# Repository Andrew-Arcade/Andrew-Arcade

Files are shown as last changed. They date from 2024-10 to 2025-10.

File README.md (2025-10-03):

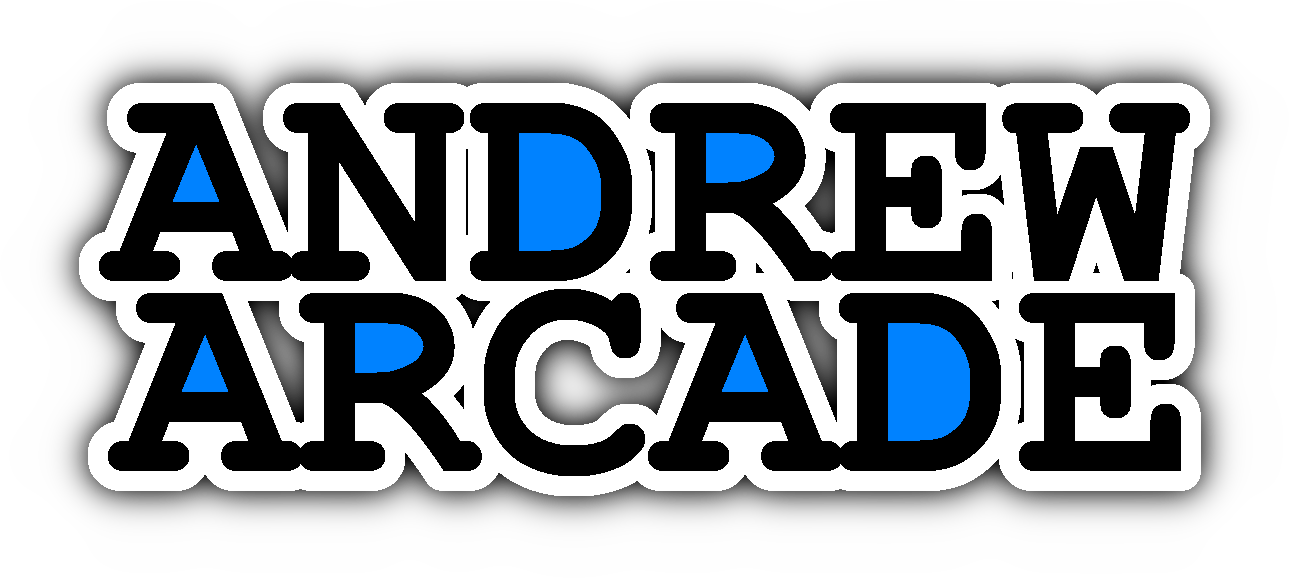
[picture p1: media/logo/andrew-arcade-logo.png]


Check out my progress in the [journal](JOURNAL.md)!

<!-- ### About Andrew Arcade

Andrew Arcade is a custom game console built with a Raspberry Pi 5 running Linux. Its main purpose is to play Unity games that I have created.

Since the Raspberry Pi 5 uses an ARM processor, Unity games can't be compiled to run on it directly. To solve this, we use a tool called Box64, which lets us run Unity games and apps on the Raspberry Pi by emulating the required architecture.

### Version 2

Version 2 of Andrew Arcade will feature a redesigned case. My goal is to make it more comfortable to use and to improve some of the mounting parts that didn’t work well in the first version. -->

## About the Project

Custom game console designed to run my Unity games.

Designed on top of the Raspberry Pi 5 running pios.

We use [box64](https://github.com/ptitSeb/box64) to run Unity games on the ARM architecture. 

## Apps
[Andrew-Arcade-Apps](https://github.com/AndrewCromar/Andrew-Arcade-Apps) (referred to as "apps repository")
> Most up to date information will be in the apps repository eventually.

### How to contribute your app

To create your own app, you'll need to submit all the source code (the full Unity project) to the apps repository. You will also need to modify the driver app to include your app (details will be provided later). Once your app is ready for release, submit a pull request (PR) to the apps repository. After your PR is approved, you can build the app and submit a second PR to this main Andrew Arcade repository.

### App file structure

Go to the [software/apps](software/apps) directory and create a new folder. Name the folder after your app using camelCase (no spaces, capitalize the first letter of each new word except for the first one). Then, place your app's build files inside the folder you just created.

### Why maintain a second repository?

Unity projects typically require a large amount of storage, while Raspberry Pi 5 devices often have limited space. As a result, the source code for the apps doesn't need to be stored directly on the device.

### More app information

For additional details about the apps or games, check out the [Andrew Arcade Apps](https://github.com/AndrewCromar/Andrew-Arcade-Apps) repository.

## BOM
> [!WARNING]
> I need to update this it is not correct atm.

- You will want an assortment of M3 screws.
- You will need to order your own pcbs (manufacturing files/instructions will come later).

| Name | URL | Notes |
|---|---|---|
| Raspberry Pi 5 | [link](https://www.raspberrypi.com/products/raspberry-pi-5/) | |
| Waveshare RP2040-Zero | [link](https://www.amazon.com/dp/B09L4YNNQH?ref_=cm_sw_r_cp_ud_ct_66QWR2T5E030FK6R5A1J_3&th=1) | Purchase with headers pre-soldered for easier assembly. |
| Adafruit HDMI Display | [link](https://www.adafruit.com/product/2232) | - Resolution: 800x480.<br> - Size: 5 inches. |
| Buttons | [link](https://www.amazon.com/dp/B08R9P3RKM?ref_=cm_sw_r_cp_ud_ct_66QWR2T5E030FK6R5A1J_6&th=1) | You need at least 11 buttons. You do not want them to be pre-wired. |
| Joysticks | [link](https://www.adafruit.com/product/512) | Soldering is required for assembly. |
| 90 Degree Headers | [link](https://www.amazon.com/PATIKIL-Header-Single-2-54mm-Plated/dp/B0C81QTKC5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) | Used to connect the joysticks to the board. |
| Button Wires | [link](https://www.amazon.com/dp/B092CW94LK?ref_=cm_sw_r_cp_ud_ct_66QWR2T5E030FK6R5A1J_5&th=1) | You need at least 11. |
| JST Connectors | [link](https://www.amazon.com/dp/B0B2R966ZY?ref_=cm_sw_r_cp_ud_ct_66QWR2T5E030FK6R5A1J_4&th=1) | - Size: 2P.<br> - Style: XH.

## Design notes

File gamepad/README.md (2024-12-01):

# How to build your gamepad.

> I may make a better version of these instructions later.

1. Gather parts.
    - Get a Raspberry Pi Pico.
    - Get six buttons.
    - Get a joystick module.
2. Wire it according to the schematic.
    - pcb/schematic.pdf
3. Install the firmware.
    - _firmware/GP2040-CE_0.7.10_Pico.uf2
4. Set the pin mappings for the controller according to my image.
    - pin-mappings.png
5. Done! You should have six buttons and the joystick.

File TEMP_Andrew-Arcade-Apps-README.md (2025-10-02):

# Andrew Arcade Apps
A collection of apps for Andrew Arcade.

> More instructions and information will be provided when the project is ready for public contributions.

---

## How to Contribute Your App
To add your app to Andrew Arcade:

1. **Upload Your App Source Code**  
   - Submit the complete source code for your app (your full Unity project) to the apps repository.

2. **Modify the Driver App**  
   - Follow the steps below to add your app to the driver app.

3. **Submit Pull Requests (PRs)**  
   - Once your app is integrated into the driver app, submit a pull request to the apps repository for review.  
   - After approval, build your app and submit a second PR to the main Andrew Arcade repository.

---

## Adding Your App to the Driver App

### 1. Upload Your App Icon
- Navigate to the [Icons folder](https://github.com/AndrewCromar/Andrew-Arcade-Apps/tree/main/Driver/Assets/Resources/Apps/Icons).
- Add your app's icon (image file) to this folder.

### 2. Fix the Icon Resolution
- Ensure your icon is a square image (width and height must be equal).  
- Note your icon's dimensions (e.g., 128x128 pixels).  
- Open the Unity project for the driver app.  
- In Unity, go to **Resources/Apps/Icons** and locate your icon.  
- Select your icon and update the **Pixels Per Unit** setting to match your icon's dimensions (e.g., set **Pixels Per Unit** to `128` if your icon is 128x128).

### 3. Create a JSON File for Your App
- Navigate to the [Apps folder](https://github.com/AndrewCromar/Andrew-Arcade-Apps/tree/main/Driver/Assets/Resources/Apps).
- Create a new JSON file named after your app, using camelCase (e.g., `myApp.json`).

### 4. Edit the JSON File
- Open the JSON file you just created.
- Use the following template and replace the placeholders with your app's details:
  ```json
  {
      "title": "Your App Name",
      "developer": "Your Developer Name",
      "icon": "icons/[your-icon-name]"
  }

- Replace [your-icon-name] with your icon's filename, including its extension.

### 5. Submit a Pull Request for the Driver App
- After completing the above steps, submit a pull request to the apps repository.
- Once approved, your app will be included in the driver app.

---

# What is camelCase?
**camelCase** is a way of naming files, variables, or other elements where:

- The first word is written in lowercase.
- Each subsequent word starts with an uppercase letter, with no spaces or underscores between words.

### Examples:
- myApp
- weatherForecast
- gameSettings

Using camelCase ensures names are readable, concise, and consistent.

---

Follow these steps carefully to contribute your app successfully. Let me know if further clarification is needed!

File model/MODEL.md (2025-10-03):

# Models

[Onshape CAD](https://cad.onshape.com/documents/3db21cff3a2dcf8b652a7395/w/82a6a37a568c22dcd730e9cf/e/2649efe94d90b2f031aeb237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)

The only tool you will need is a 3d printer as everything is 3d printable for the assemble of Andrew Arcade, the only thing not 3d printable is the pcb. 

In the future I will make instructions with images but for now just use the master assembly in the onshape design as reference.

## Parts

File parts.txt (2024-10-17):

Raspberry Pi 5 - https://www.raspberrypi.com/products/raspberry-pi-5/
	- Price: $80.

Adafruit HDMI Display - https://www.adafruit.com/product/2232
	- Price: $60.
	- Dimensions: 800x480
	- Size: 5".

Power Button:
	- 17.3 mm max diameter
	- 13.0 mm fit diameter
	- 21.4 mm height
	- 8.3 mm height (top of button to skinny part)

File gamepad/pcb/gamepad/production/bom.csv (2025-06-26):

Designator | Footprint | Quantity | Value | LCSC Part #
CARDINAL_DOWN1, CARDINAL_LEFT1, CARDINAL_RIGHT1, CARDINAL_UP1, DPAD_EAST1, DPAD_NORTH1, DPAD_SOUTH1, DPAD_WEST1, OPERATORS_MINUS1, OPERATORS_PLUS1 | JST_XH_B2B-XH-A_1x02_P2.50mm_Vertical | 10 | Conn_01x02
JOYSTICK_LEFT1, JOYSTICK_RIGHT1 | JST_PH_B5B-PH-K_1x05_P2.00mm_Vertical | 2 | Conn_01x05
U3 | MODULE_RP2040-ZERO | 1 | RP2040-ZERO

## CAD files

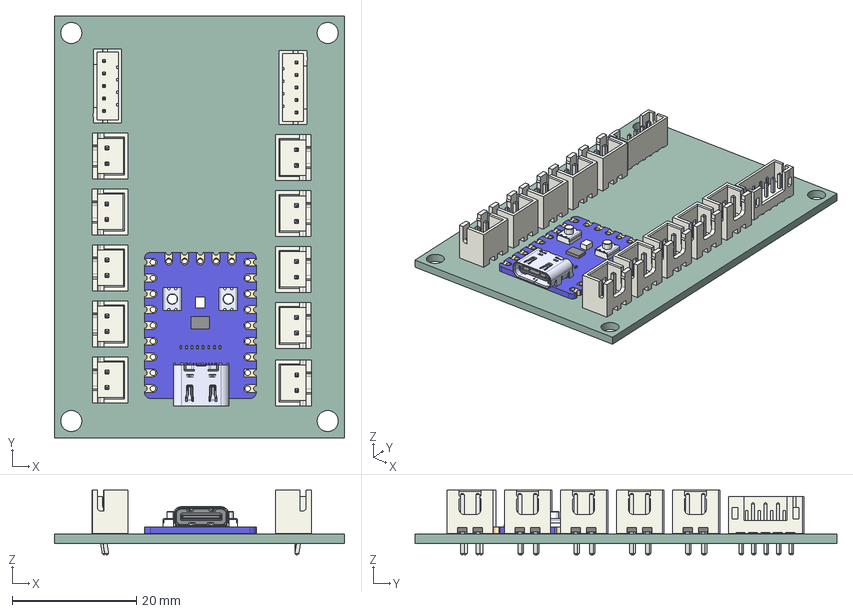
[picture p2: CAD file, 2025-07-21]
gamepad/pcb/gamepad.step
46.6 x 67.8 x 10.4 mm
JST_XH_B2B-XH-A_1x02_P2.50mm_Vertical x 10
JST_PH_B5B-PH-K_1x05_P2.00mm_Vertical x 2
RP2040-ZERO
gamepad_PCB

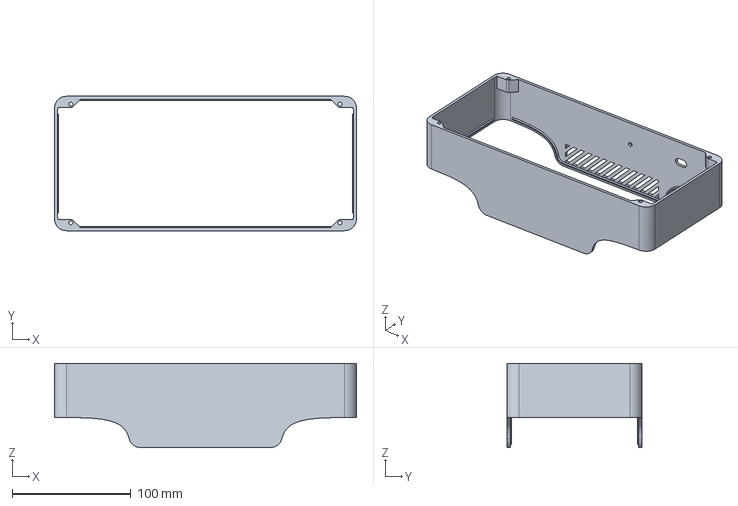
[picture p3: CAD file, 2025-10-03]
model/Wall.step
254.0 x 113.1 x 70.8 mm

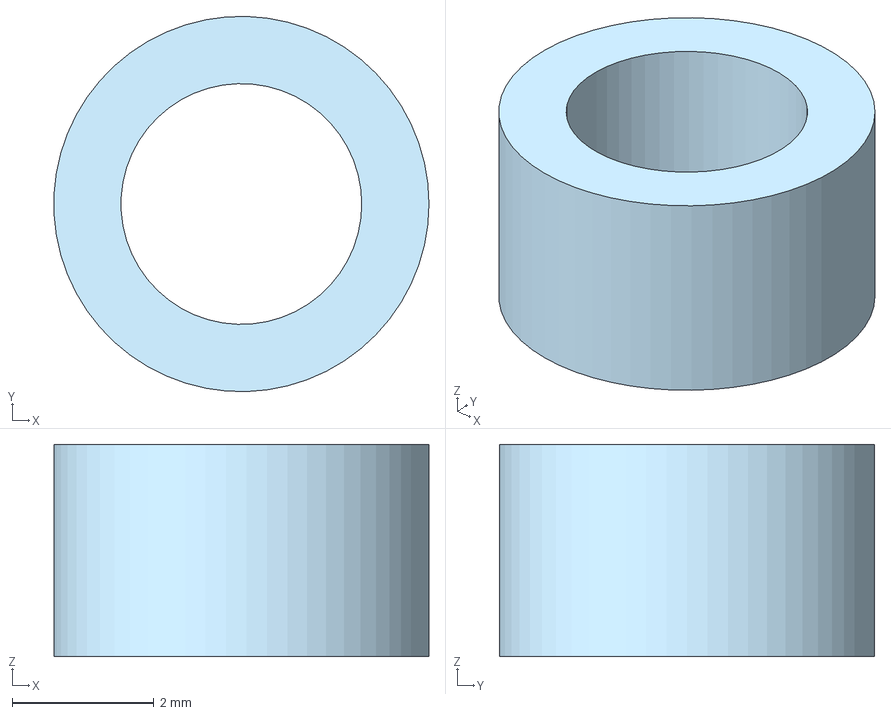
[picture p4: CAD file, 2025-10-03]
model/Spacers - Pi5 Spacer Top.step
5.30 x 5.30 x 3.00 mm

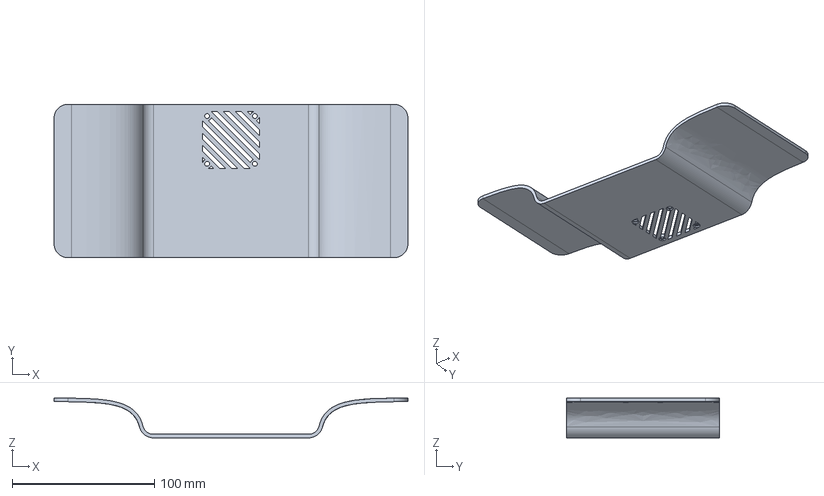
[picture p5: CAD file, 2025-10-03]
model/Back Plate.step
248.7 x 107.8 x 27.9 mm

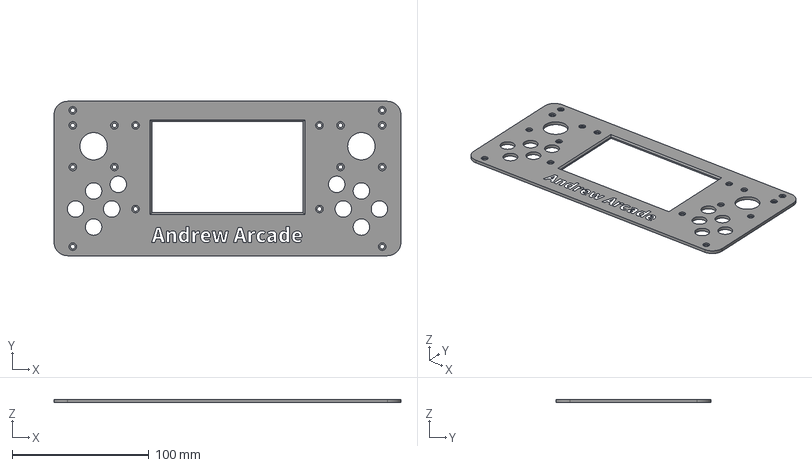
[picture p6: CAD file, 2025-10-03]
model/Front Panel.step
254.0 x 113.1 x 2.54 mm

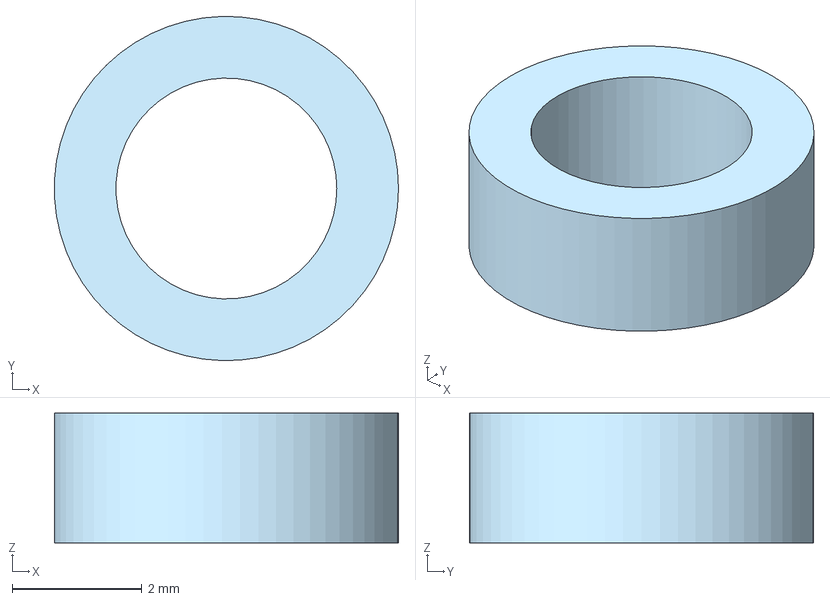
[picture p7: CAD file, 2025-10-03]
model/Spacers - Pi5 Spacer Bottom.step
5.30 x 5.30 x 2.00 mm

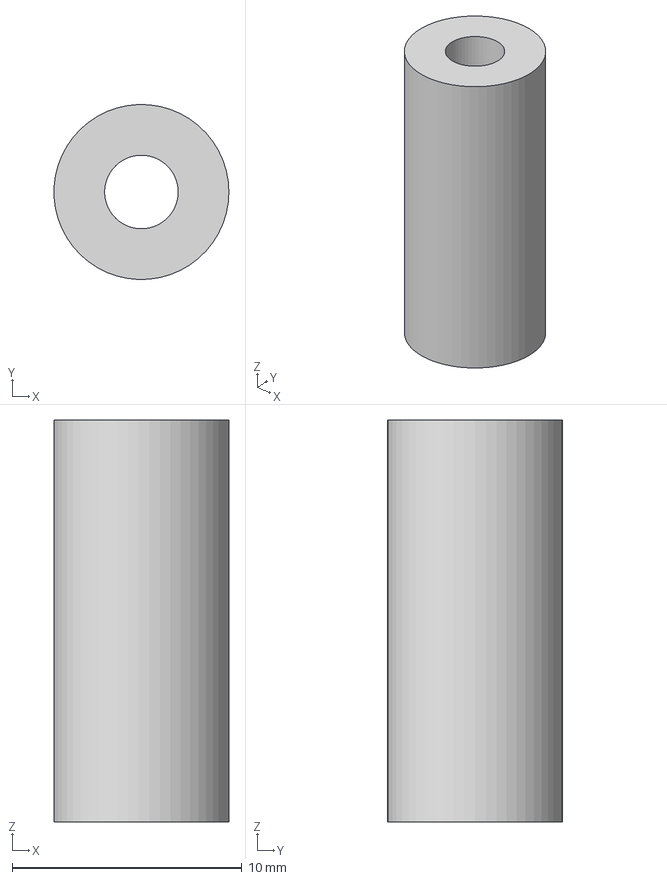
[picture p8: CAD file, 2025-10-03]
model/Joystick Mount.step
7.61 x 7.62 x 17.5 mm

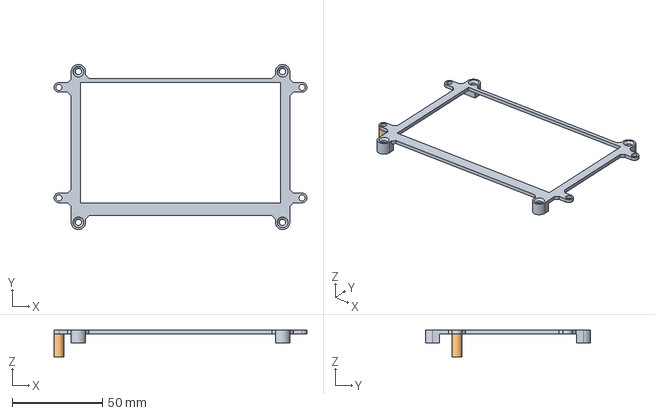
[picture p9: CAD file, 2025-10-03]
model/Display Mount.step
140.0 x 91.4 x 14.8 mm

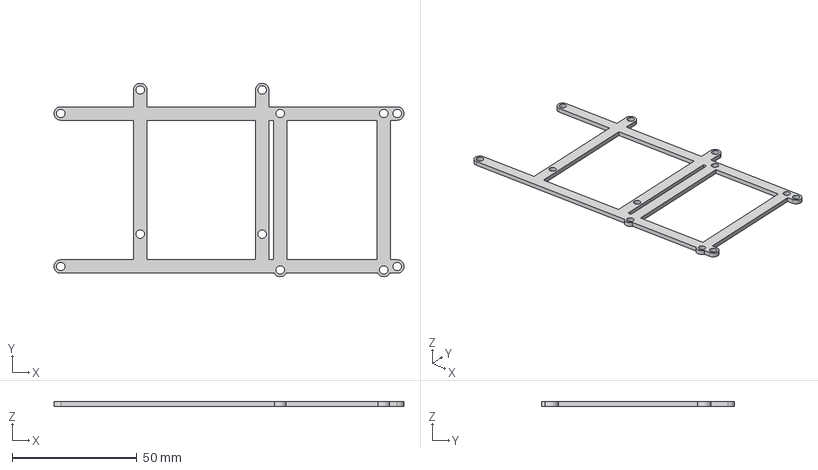
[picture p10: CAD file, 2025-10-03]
model/Pis Mount.step
140.0 x 77.4 x 2.00 mm

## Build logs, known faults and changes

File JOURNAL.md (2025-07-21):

---
title: "Andrew Arcade"
author: "Andrew Cromar"
description: "A custom game console designed to run Unity Games."
created_at: "2025-05-22"
---

# July 21th: Redesigned the PCB to be smaller.

- I had to move the rp5 over a bit so I needed to make the pcb smaller.

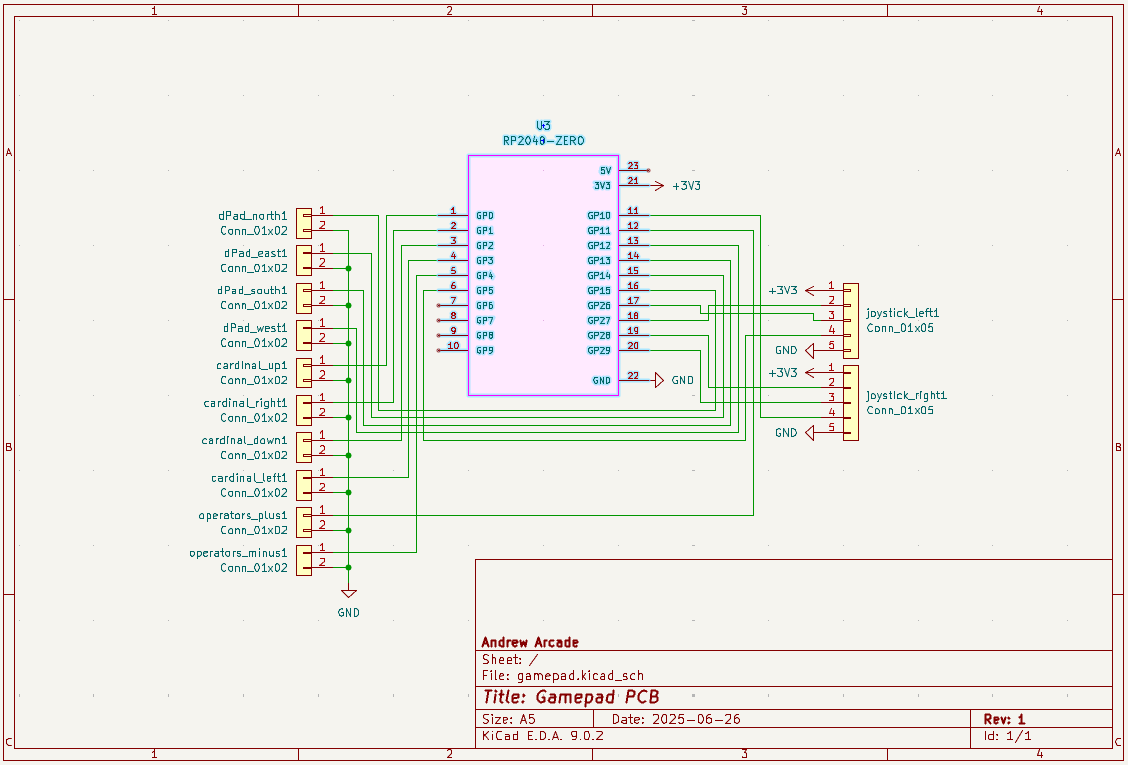
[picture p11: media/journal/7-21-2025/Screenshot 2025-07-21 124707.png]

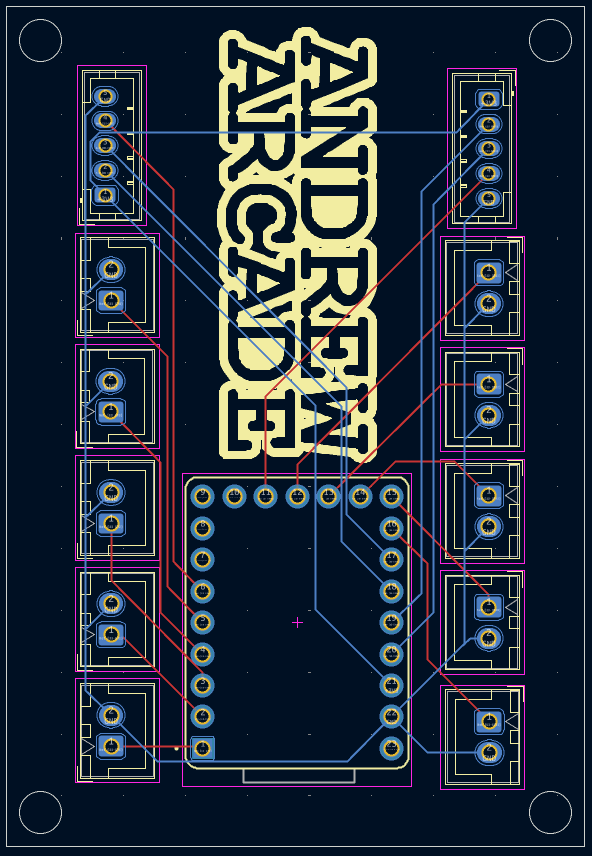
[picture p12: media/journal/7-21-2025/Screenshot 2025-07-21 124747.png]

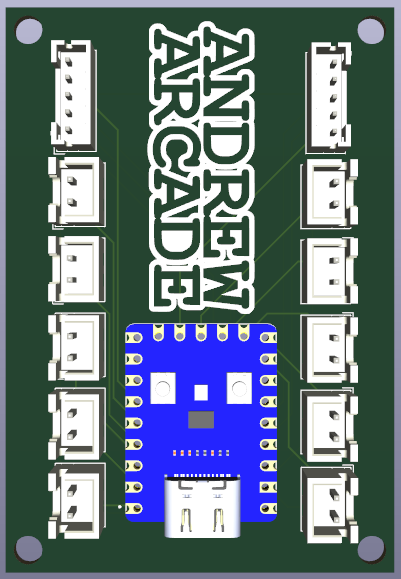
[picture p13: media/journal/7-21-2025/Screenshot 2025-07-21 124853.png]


**Total time spent: 2 hours**

# June 25th: Made a few updates to different parts.

- I updated the layout of the front panel.
    - I still am not 100% happy with where the +/- buttons are but It's good enough for now.
- I updated the pcb to work with all the buttons and to have more ideally placed connectors.

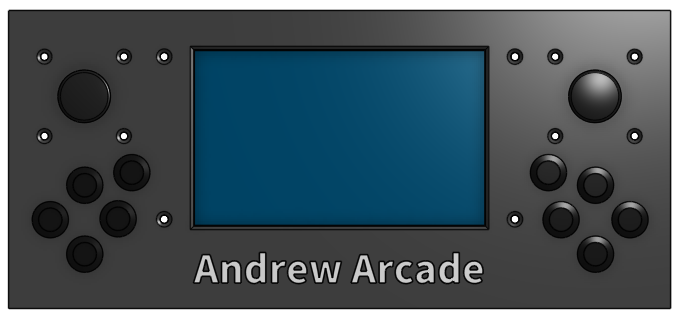
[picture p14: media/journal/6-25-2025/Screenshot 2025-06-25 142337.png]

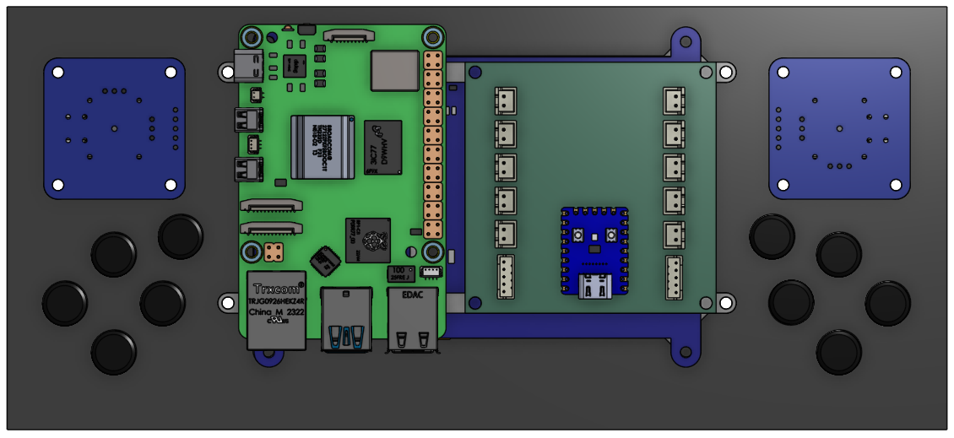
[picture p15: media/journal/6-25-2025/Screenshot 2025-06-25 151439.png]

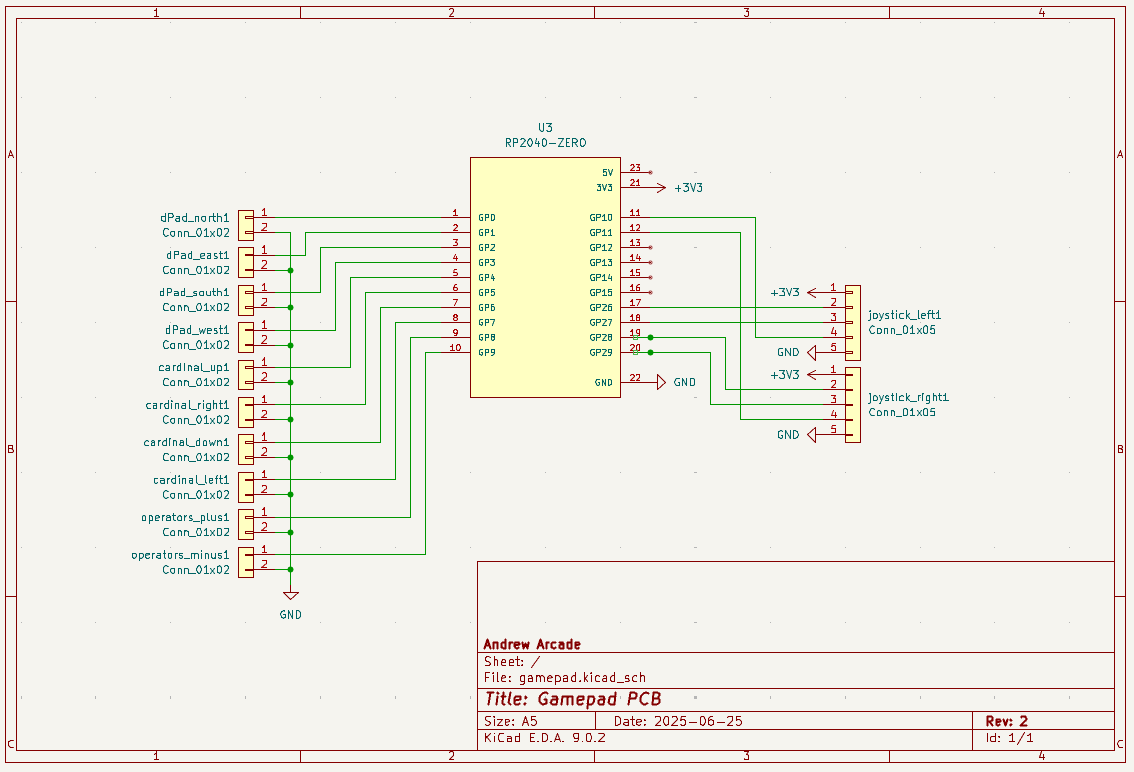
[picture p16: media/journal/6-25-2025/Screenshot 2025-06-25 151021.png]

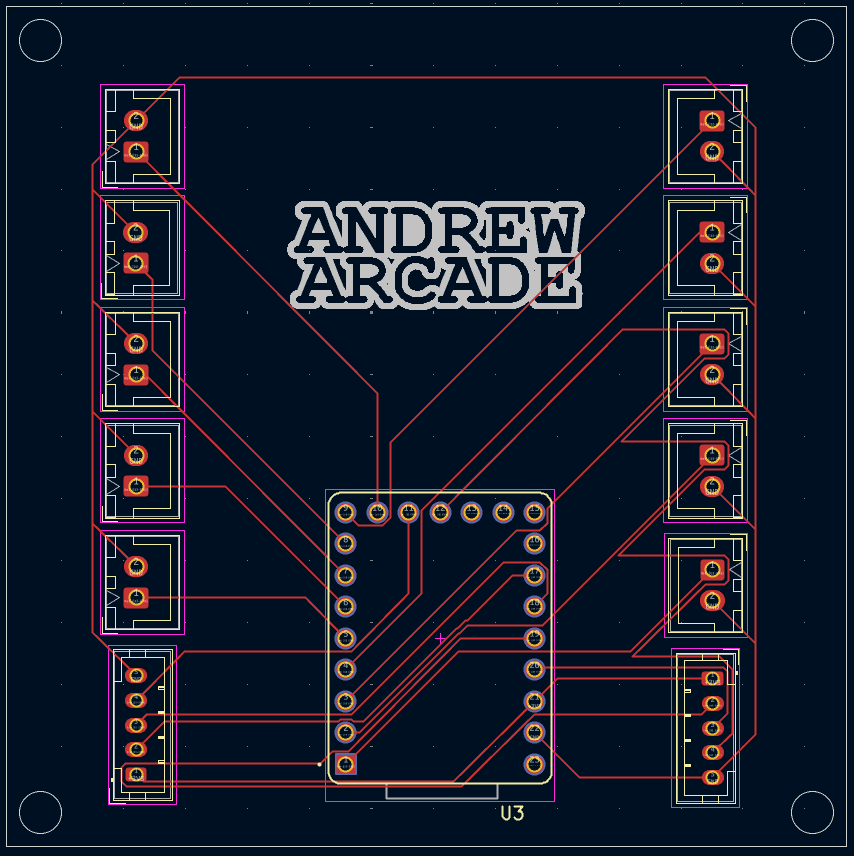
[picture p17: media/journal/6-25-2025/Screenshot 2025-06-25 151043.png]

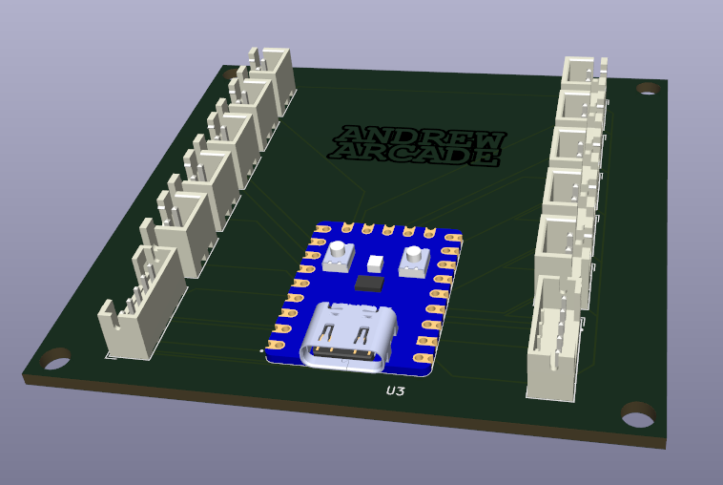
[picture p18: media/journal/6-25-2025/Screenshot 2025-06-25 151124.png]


**Total time spent: 2 hours**

# June 4th: Decided to switch to a Waveshare Zero.

- I wanted to use two joysticks for my project, but the Raspberry Pi Pico didn’t have enough analog pins. So, I switched to the Waveshare 2040 Zero, which uses the same RP2040 chip as the Pico but provides 4 analog pins, enough for both joysticks (2 pins each for X and Y on both the left and right joysticks).
- I updated the PCB design to use the new board. This involved finding the correct footprints, symbols, and a CAD model for the Waveshare 2040 Zero.
- I’ve updated the schematic, but I haven’t finished routing the PCB traces yet.

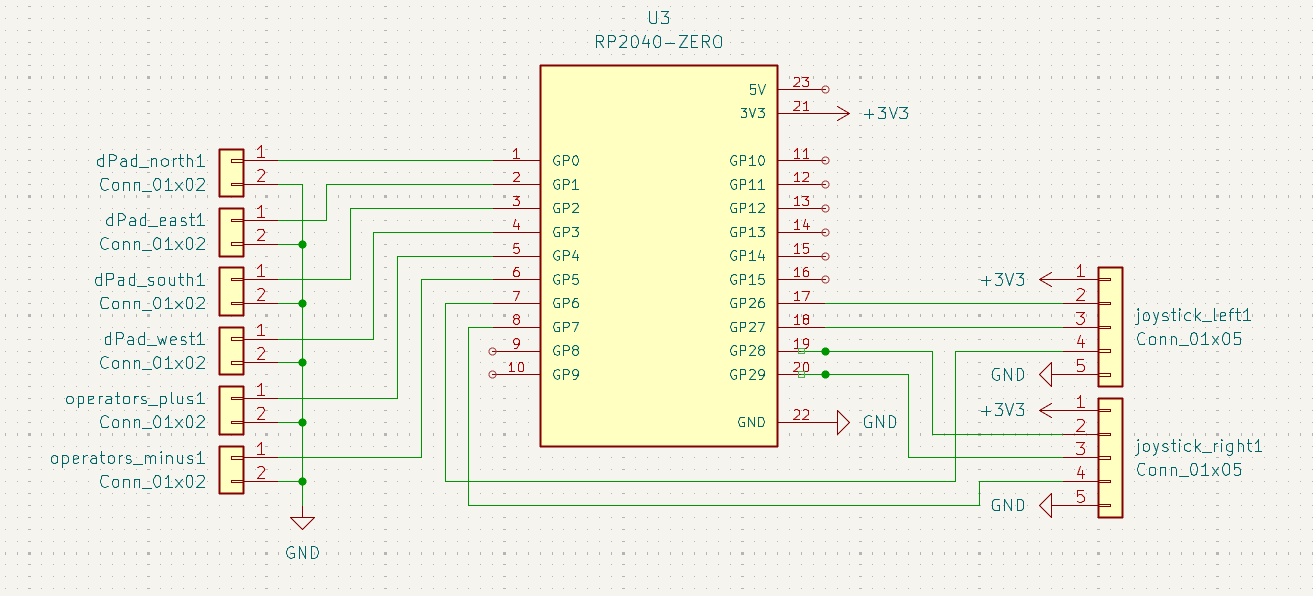
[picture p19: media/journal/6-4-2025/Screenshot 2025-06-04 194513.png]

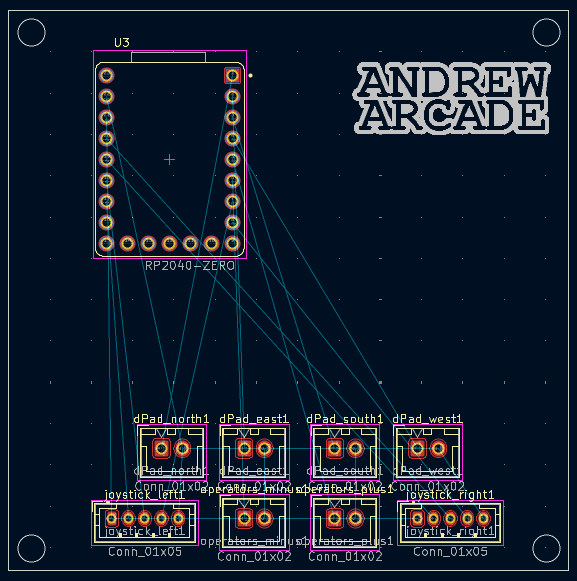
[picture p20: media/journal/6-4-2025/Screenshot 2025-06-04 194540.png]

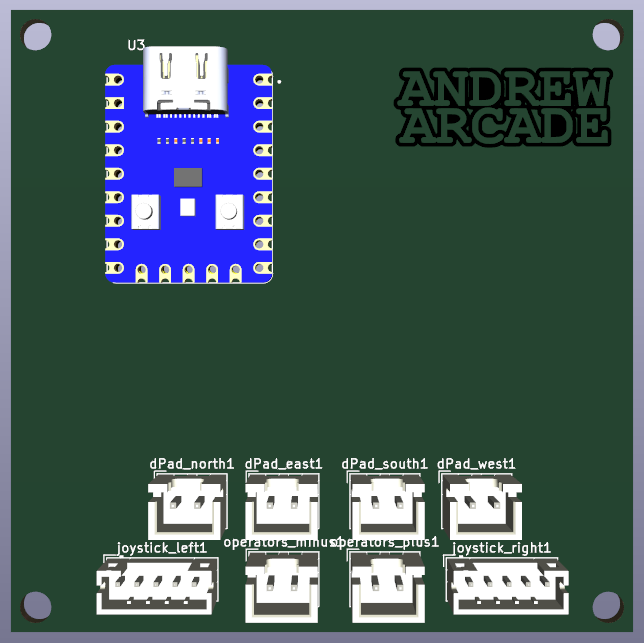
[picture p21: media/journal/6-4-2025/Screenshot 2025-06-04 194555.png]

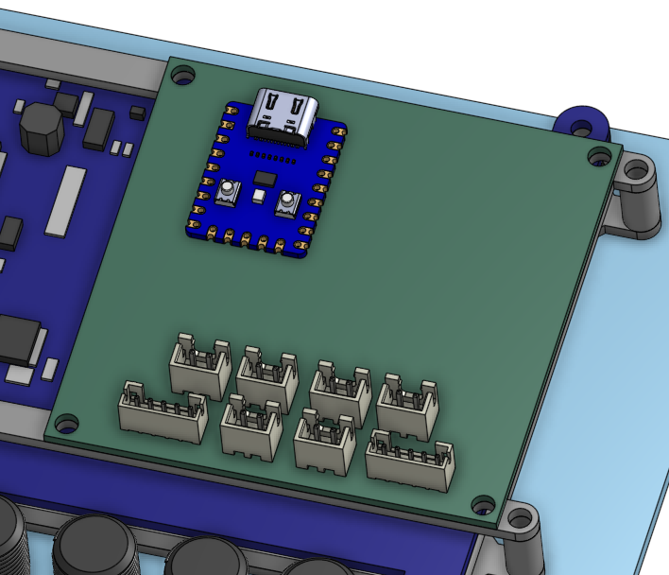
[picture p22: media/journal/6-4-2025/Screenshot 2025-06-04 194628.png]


**Total time spent: 1 hour 30 mins**

# May 30th: Made some progress on the PCB.

- Continued developing the gamepad PCB:
    - Located and added the necessary KiCad component libraries.
    - Connected all components together in the schematic.
    - Finished routing all the PCB traces.

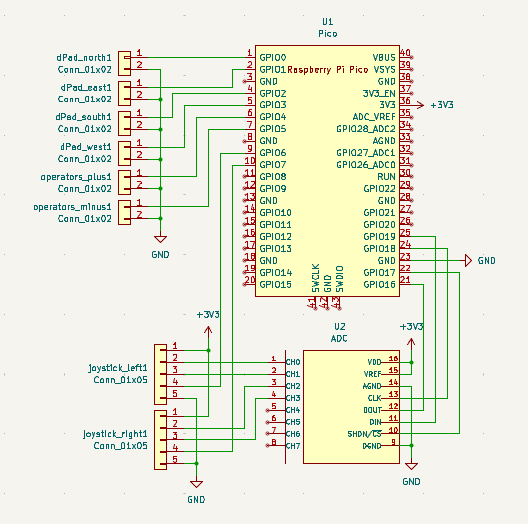
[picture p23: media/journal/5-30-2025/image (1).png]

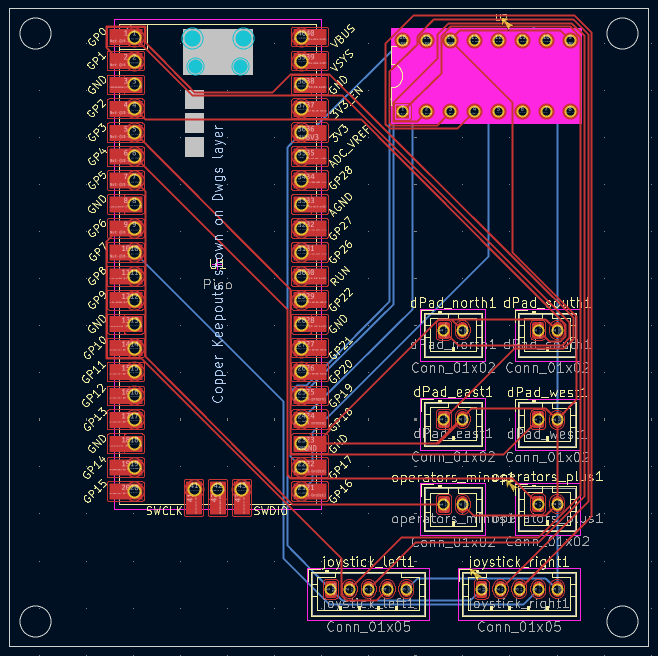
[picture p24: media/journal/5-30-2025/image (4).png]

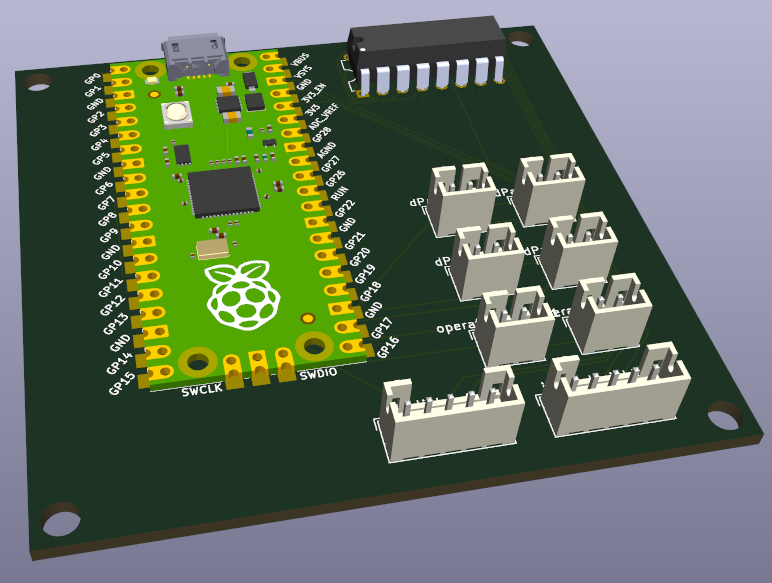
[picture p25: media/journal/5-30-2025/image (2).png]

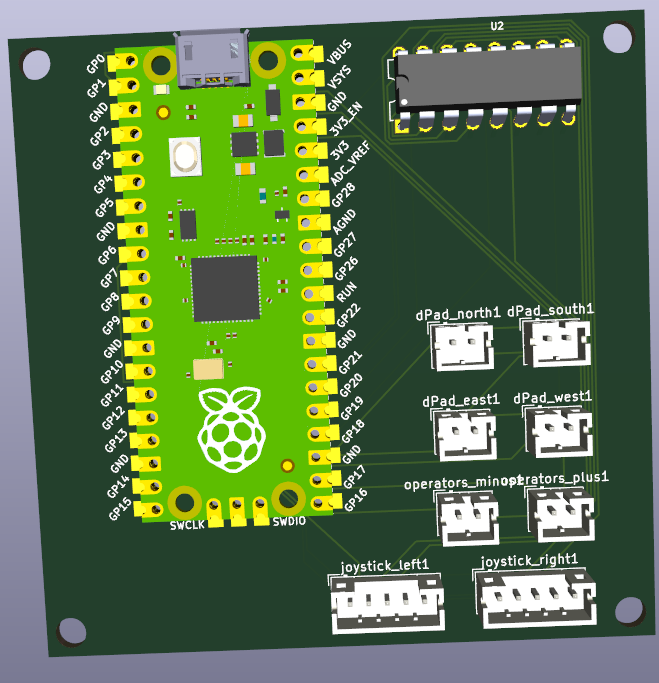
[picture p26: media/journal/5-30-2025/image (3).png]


**Total time spent: 1 hour 15 mins**

# May 24th: Worked on the cad model.

- Creadted a front panel for everything to mount to.
    - Button positions are not final.
- Created parts to hold the joystick module to the front panel.
- Created a button to be used in the main cad assembly.

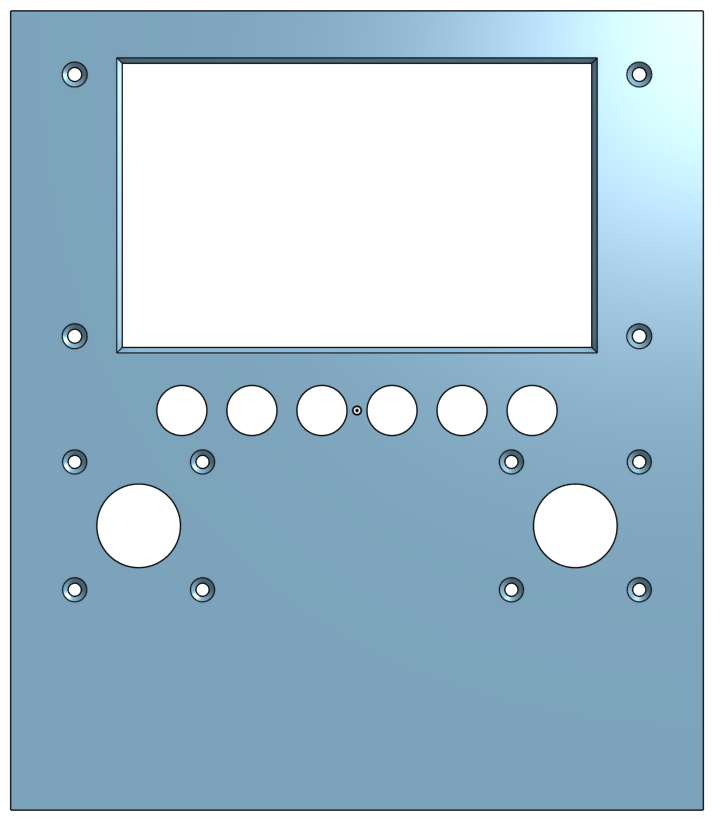
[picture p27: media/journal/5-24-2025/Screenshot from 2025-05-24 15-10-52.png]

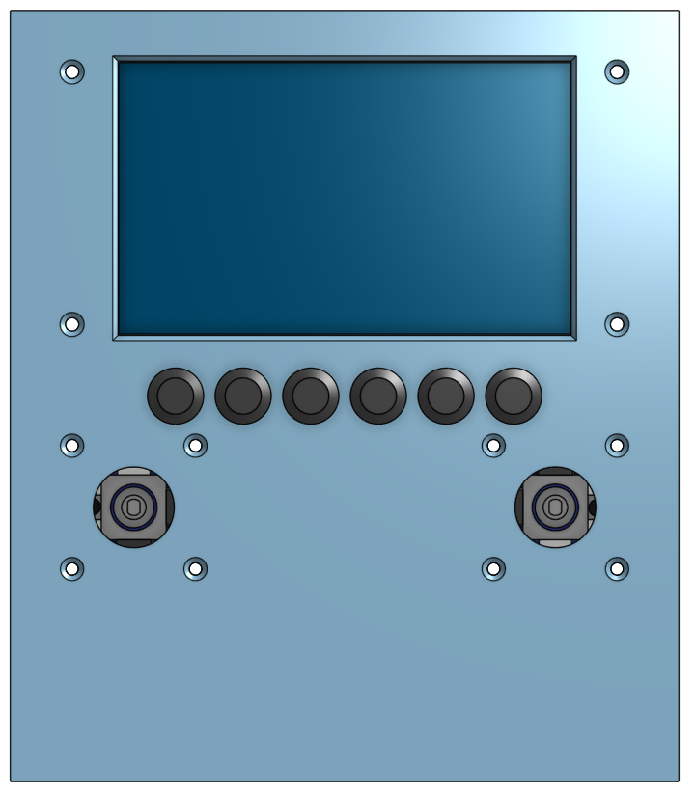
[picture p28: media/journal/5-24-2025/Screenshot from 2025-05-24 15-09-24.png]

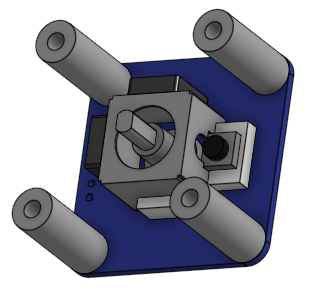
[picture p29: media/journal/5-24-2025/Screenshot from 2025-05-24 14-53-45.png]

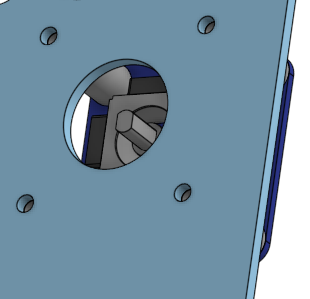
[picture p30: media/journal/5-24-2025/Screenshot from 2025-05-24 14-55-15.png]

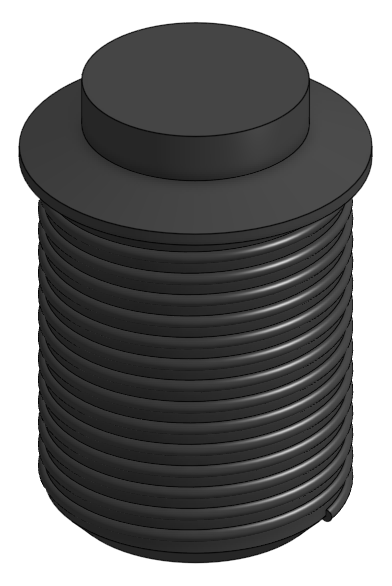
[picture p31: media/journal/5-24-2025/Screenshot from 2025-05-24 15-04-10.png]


**Total time spent: 1 hour**

# May 22nd: Started work on the gamepad PCB.

- I'm still new to KiCad but I'm starting to learn how to use it. I want to make my project more clean and organized.

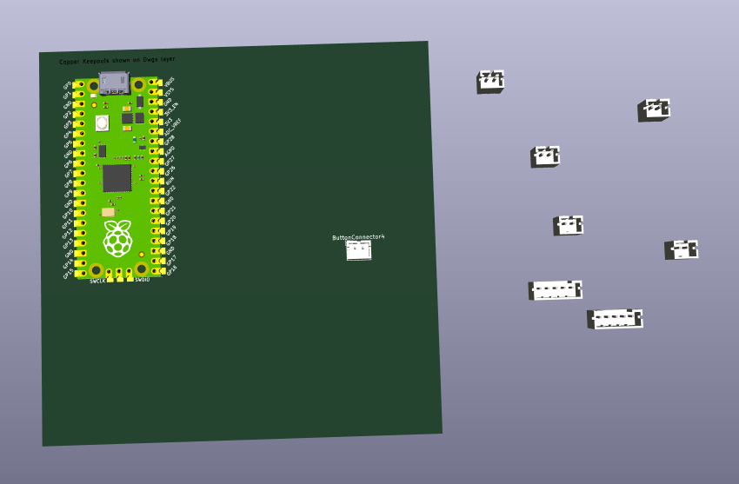
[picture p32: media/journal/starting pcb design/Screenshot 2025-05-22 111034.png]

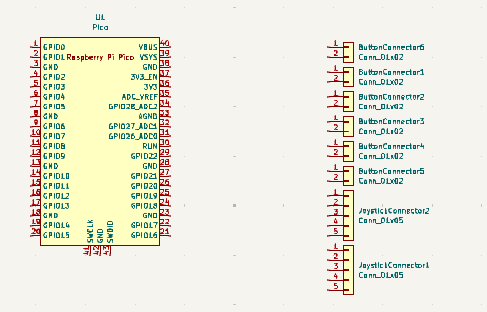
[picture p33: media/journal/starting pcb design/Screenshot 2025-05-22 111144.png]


**Total time spent: 1 hour**

# May 21st: Designed a screen mount.

- I designed a mount in onshape to hold my screen in place and have nice holes for mounting.

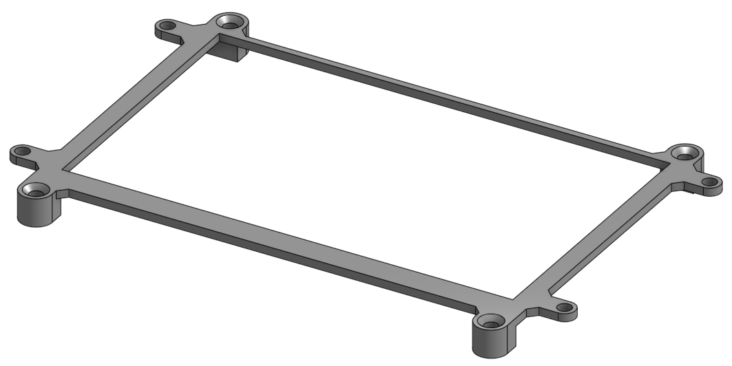
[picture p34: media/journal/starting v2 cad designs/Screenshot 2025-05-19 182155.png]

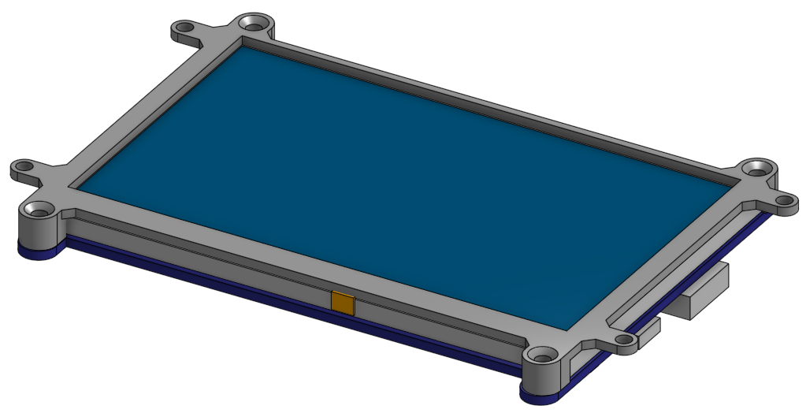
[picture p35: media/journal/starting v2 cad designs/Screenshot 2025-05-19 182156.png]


**Total time spent: 1 hour**

<details>
    <summary>old stuff from v1</summary>
    <details>
    <summary>Jan 23, 2025: FINISHED!!!!</summary><br>
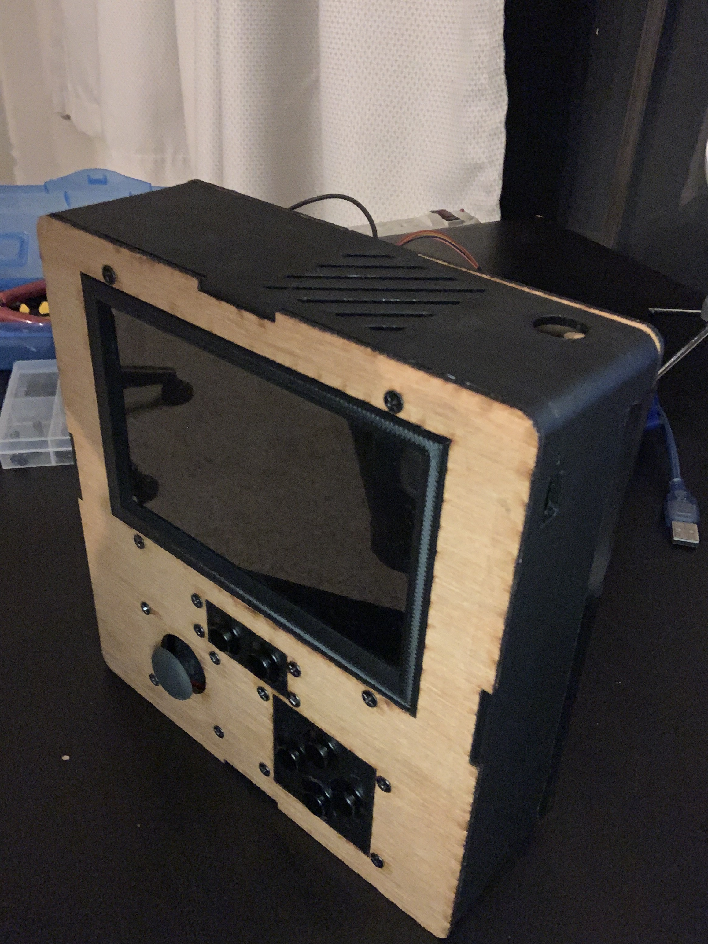
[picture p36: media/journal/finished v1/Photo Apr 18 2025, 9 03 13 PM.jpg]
        
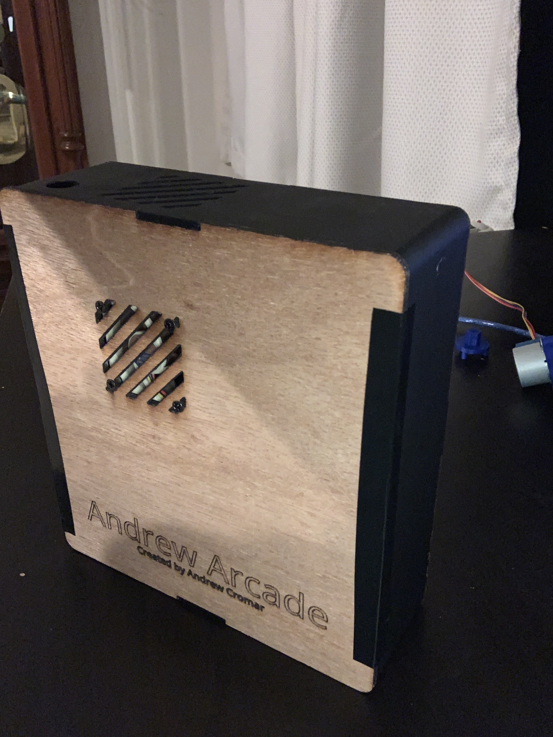
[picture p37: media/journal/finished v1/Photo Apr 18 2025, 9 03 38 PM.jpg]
        
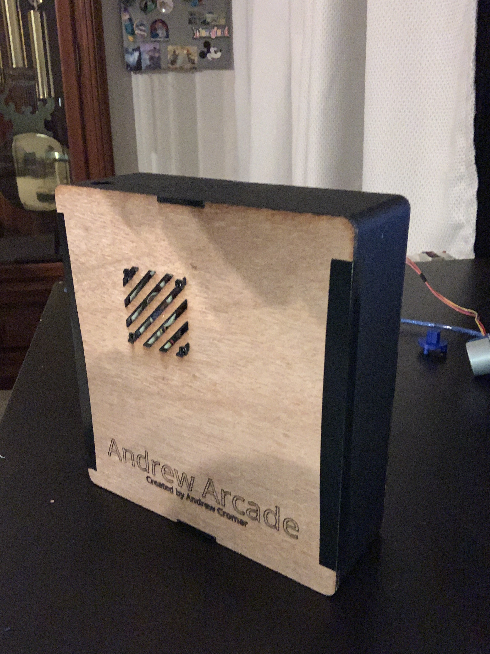
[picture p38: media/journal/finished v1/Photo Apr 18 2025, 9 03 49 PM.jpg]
        
    </details>
    <details>
    <summary>Jan 23, 2025: Beginning assembly!</summary><br>
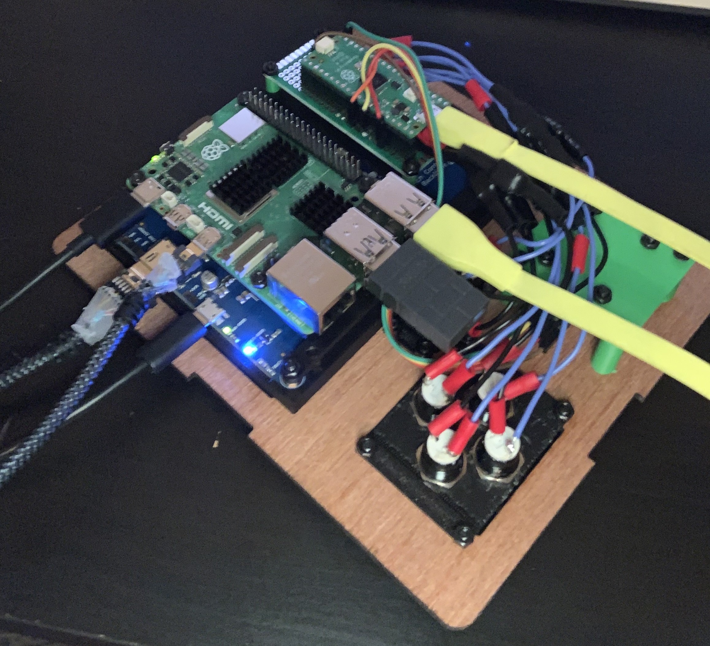
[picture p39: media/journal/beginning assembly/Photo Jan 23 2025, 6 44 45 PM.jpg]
        
    </details>
    <details>
    <summary>Jan 22, 2025: New controller setup.</summary><br>
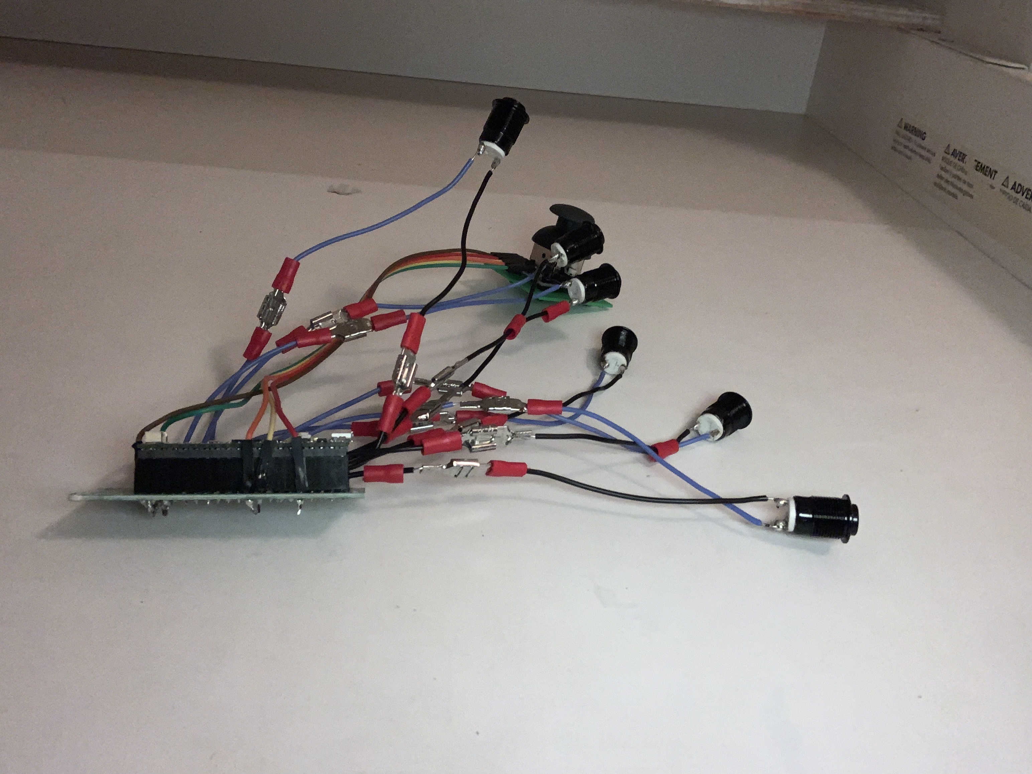
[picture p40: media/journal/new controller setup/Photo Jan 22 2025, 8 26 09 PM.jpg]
        
        
        
    </details>
    <details>
    <summary>Jan 11, 2025: New mounts for the pis.</summary><br>
        
    </details>
    <details>
    <summary>December 7, 2024: Well the final version of the case is coming along.</summary><br>
        
        
        
    </details>
    <details>
    <summary>December 1, 2024: GOT THE CONTROLLER WORKING FINALLY</summary><br>
        Sorry no pictures for this one but I finally got the controller working. :)
    </details>
    <details>
    <summary>November 15, 2024: Final (hopefully) front plate printed + started to assemble.</summary><br>
        
        
    </details>
    <details>
    <summary>October 29, 2024: New buttons arrived.</summary><br>
        
        
    </details>
    <details>
    <summary>October 28, 2024: Working on front panel v3.</summary><br>
        
    </details>
    <details>
    <summary>October 22, 2024: Started wiring up the buttons to ground.</summary><br>
        
    </details>
    <details>
    <summary>October 22, 2024: Front panel v2 printed.</summary><br>
        
        
    </details>
    <details>
    <summary>October 22, 2024: Print failed but I can test the button fit.</summary><br>
        
    </details>
    <details>
    <summary>October 20, 2024: Working on the pi5 mount.</summary><br>
        
    </details>
    <details>
    <summary>October 19, 2024: Working on front panel v2.</summary><br>
        
        
    </details>
    <details>
    <summary>October 18, 2024: Front panel v1 printed.</summary><br>
        
        
        
    </details>
    <details>
    <summary>October 18, 2024: Controller wiring testing done.</summary><br>
        
    </details>
    <details>
    <summary>October 17, 2024: Working on case model.</summary><br>
        
    </details>
    <details>
    <summary>October 2, 2024: Controller Working (not plus and minus).</summary><br>
        
        
        
        
        
    </details>
</details>

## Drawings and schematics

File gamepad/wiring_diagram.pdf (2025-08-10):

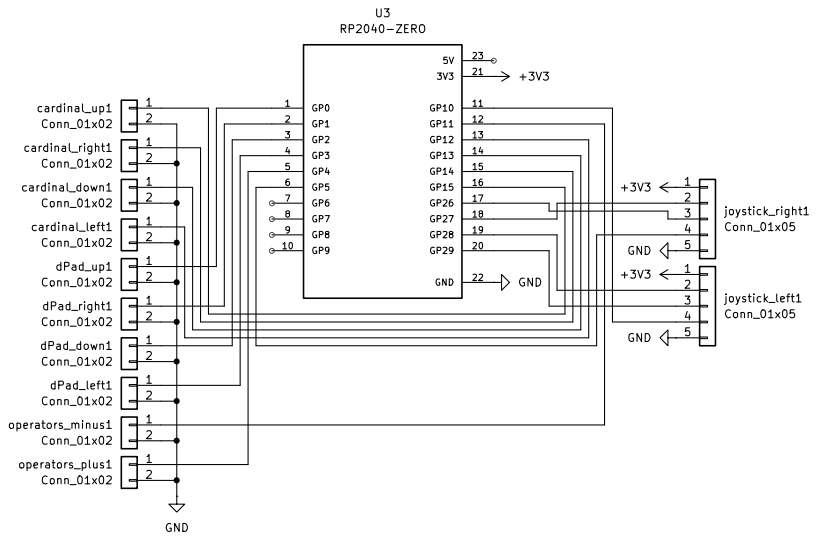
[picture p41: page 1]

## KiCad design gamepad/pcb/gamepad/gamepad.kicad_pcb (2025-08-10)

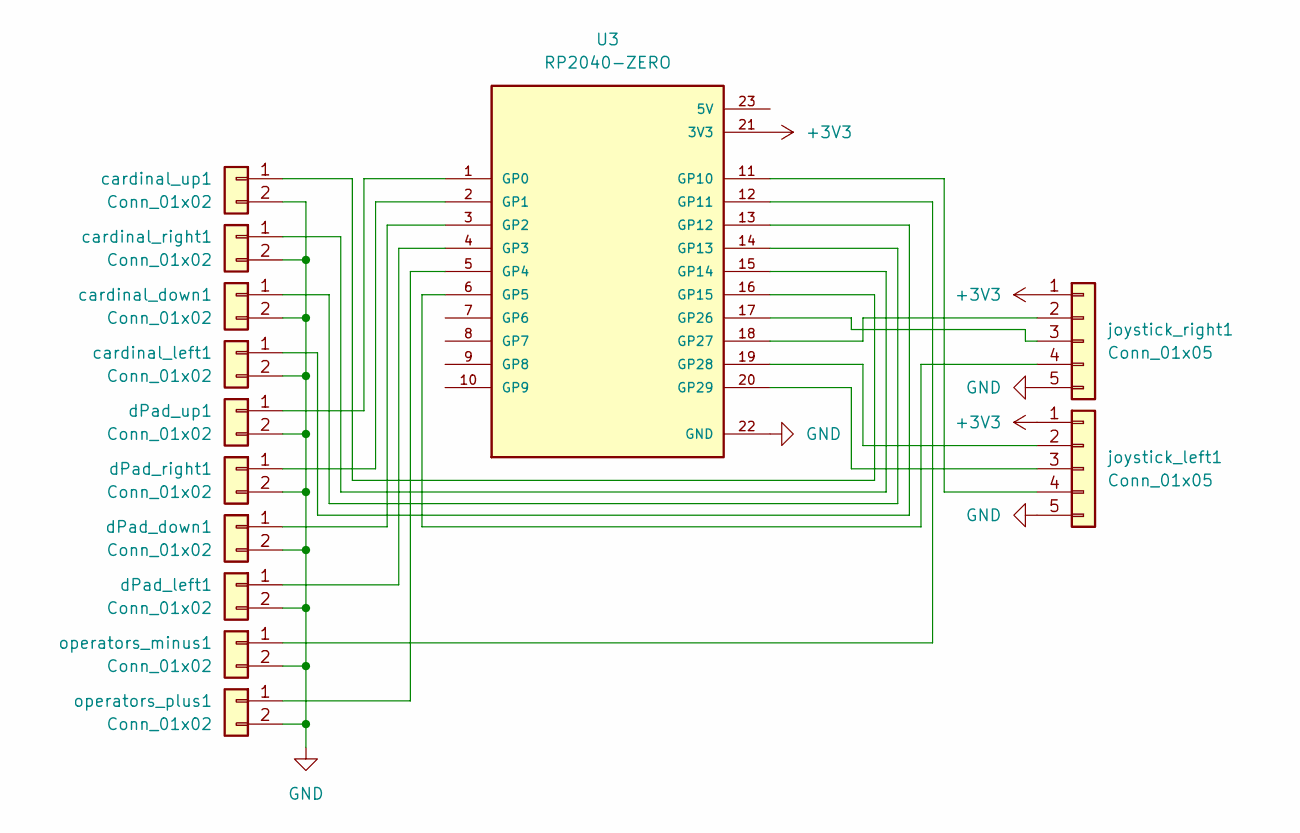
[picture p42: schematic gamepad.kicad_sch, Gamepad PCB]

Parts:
U3: RP2040-ZERO; MODULE_RP2040-ZERO; PARTREV NA
cardinal_down1: Conn_01x02; JST_XH_B2B-XH-A_1x02_P2.50mm_Vertical
cardinal_left1: Conn_01x02; JST_XH_B2B-XH-A_1x02_P2.50mm_Vertical
cardinal_right1: Conn_01x02; JST_XH_B2B-XH-A_1x02_P2.50mm_Vertical
cardinal_up1: Conn_01x02; JST_XH_B2B-XH-A_1x02_P2.50mm_Vertical
dPad_down1: Conn_01x02; JST_XH_B2B-XH-A_1x02_P2.50mm_Vertical
dPad_left1: Conn_01x02; JST_XH_B2B-XH-A_1x02_P2.50mm_Vertical
dPad_right1: Conn_01x02; JST_XH_B2B-XH-A_1x02_P2.50mm_Vertical
dPad_up1: Conn_01x02; JST_XH_B2B-XH-A_1x02_P2.50mm_Vertical
joystick_left1: Conn_01x05; JST_PH_B5B-PH-K_1x05_P2.00mm_Vertical
joystick_right1: Conn_01x05; JST_PH_B5B-PH-K_1x05_P2.00mm_Vertical
operators_minus1: Conn_01x02; JST_XH_B2B-XH-A_1x02_P2.50mm_Vertical
operators_plus1: Conn_01x02; JST_XH_B2B-XH-A_1x02_P2.50mm_Vertical

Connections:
+3V3: U3.21 (3V3), joystick_left1.1, joystick_right1.1
GND: U3.22 (GND), cardinal_down1.2, cardinal_left1.2, cardinal_right1.2, cardinal_up1.2, dPad_down1.2, dPad_left1.2, dPad_right1.2, dPad_up1.2, joystick_left1.5, joystick_right1.5, operators_minus1.2, operators_plus1.2
unnamed: U3.1 (GP0), dPad_up1.1
unnamed: U3.2 (GP1), dPad_right1.1
unnamed: U3.3 (GP2), dPad_down1.1
unnamed: U3.4 (GP3), dPad_left1.1
unnamed: U3.5 (GP4), operators_plus1.1
unnamed: U3.6 (GP5), joystick_right1.4
unnamed: U3.11 (GP10), joystick_left1.4
unnamed: U3.12 (GP11), operators_minus1.1
unnamed: U3.13 (GP12), cardinal_left1.1
unnamed: U3.14 (GP13), cardinal_down1.1
unnamed: U3.15 (GP14), cardinal_right1.1
unnamed: U3.16 (GP15), cardinal_up1.1
unnamed: U3.17 (GP26), joystick_right1.3
unnamed: U3.18 (GP27), joystick_right1.2
unnamed: U3.19 (GP28), joystick_left1.2
unnamed: U3.20 (GP29), joystick_left1.3

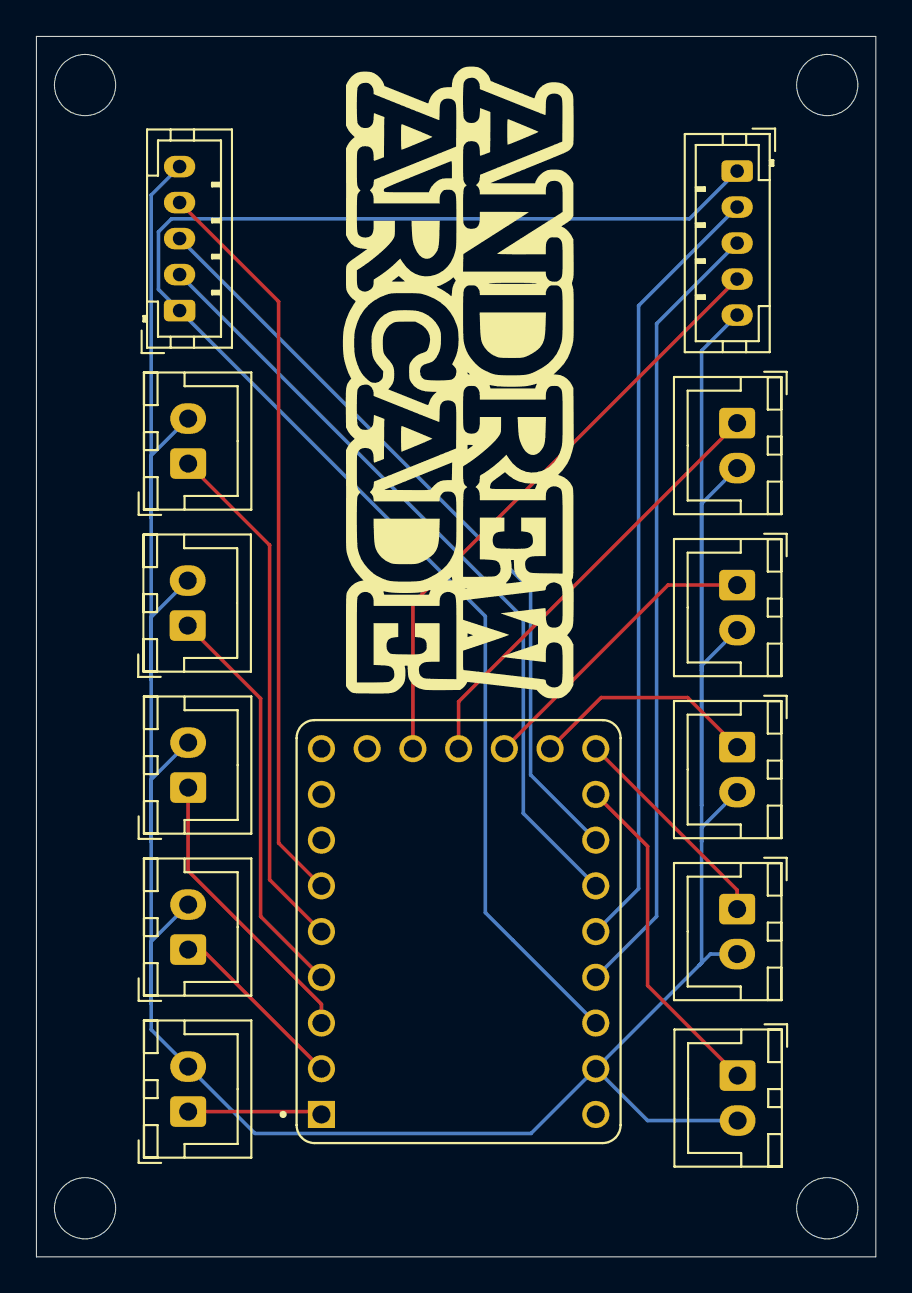
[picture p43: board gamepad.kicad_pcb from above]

Board: 2 copper layers, 46.6 x 67.8 mm, 13 parts (0 on the bottom side), 18 nets.

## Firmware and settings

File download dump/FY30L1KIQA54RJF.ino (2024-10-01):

//  **********************************************************************//
//  author: Joram de Poel                                                 //
//  date:   8-7-2016                                                      //
//  version: 1.3                                                          //
//  email: joramdepoel@gmail.com                                          //
//  **********************************************************************//
//
//  This code is free to use, edit and distrubate as long as you use it for non profit projects
//
//  this code is writen to use analog joysticks in the easiest way possible and with the most options
//  this code deals with ofsets, limited range, inverted axis and many other problems with joysticks
//  this code uses the map_float function, if you didnt already include this in your arduino core, 
//  just uncomment the function at the bottom

//*****************define your pins here***********************************************//
#define joystick_X A1    //joystick  X-as
#define joystick_Y A0    //joystick  Y-as
#define button_2 2       // button on d2


//****************define the min, max and center you want for your joystick here*******//
long range_X_min = 1000;           //lowest X value
long range_X_max = 10000;          //highest X value
long range_X_center = 0;           //X center calue
unsigned long deadZone_X = 1;      //deadzone X, return center value for center +- deadzone(in steps of 1/1024)

float range_Y_min = 0;             //lowest Y value
float range_Y_max = 1023;          //highest Y value
float range_Y_center = 512;        //Y center value
unsigned long deadZone_Y = 1;      //deadzone Y, return center value for center +- deadzone(in steps of 1/1024)


//***************calibration variables************************************************//
int val_X, val_Y;

unsigned long X_CENTER, X_MIN, X_MAX;
unsigned long Y_CENTER, Y_MIN, Y_MAX;

unsigned long cal_X;
unsigned long cal_Y;


//************setup******************************************************************//

void setup() {
  Serial.begin(9600);
  pinMode(joystick_X, INPUT);
  pinMode(joystick_Y, INPUT);
  pinMode(button_2, INPUT_PULLUP);    //we pull this pin high to avoid a floating pin
  calibrate();
}

long joy_X(long X) {
  X += (X_CENTER-512);   //should always be 512
  if (X <= 512) {
    X = mapfloat(X, X_MIN, X_CENTER, range_X_min, range_X_center);   //min,center to range min, range center
    return X;
  }
  else if (X > 512) {
    X = mapfloat(X, 512, 1024 + X_CENTER, range_X_center, range_X_max);
    return X;
  }
}

long joy_Y(long Y) {
  Y += (Y_CENTER-512);
  if (Y <= range_Y_center) {
    Y = mapfloat(Y, Y_CENTER, 512, 0, 512);
    return Y;
  }
  else if (Y > range_Y_center) {
    Y = mapfloat(Y, 512, 1024 + Y_CENTER, 512, 1024);
    return Y;
  }
}

void loop() {
  val_X = analogRead(joystick_X);
  Serial.print(joy_X(val_X)); Serial.print(" : ");
  delay(50);
  val_Y = analogRead(joystick_Y);
  Serial.println(joy_Y(val_Y));
  delay(50);
  if (digitalRead(button_2) == LOW) {
    calibrate();    //you can call any function you want here, this is just to show the possibilities
  }
}

void set_range_X(float min, float max, float center) {
  range_X_min = min;
  range_X_max = max;
  range_X_center = center;
}

void set_range_Y(float min, float max, float center) {
  range_Y_min = min;
  range_Y_max = max;
  range_Y_center = center;
}

void calibrate() {
  Serial.println("\n---calibrating joystick---\n");
  Serial.println("place the joystick in the center position");
  cal_X = 0;
  cal_Y = 0;
  delay(2500);
  Serial.print("calibrating center");
  for (int i = 0; i < 100; i++) {
    Serial.print(".");
    cal_X += analogRead(joystick_X);
    delay(5);
    cal_Y += analogRead(joystick_Y);
    delay(5);
  }
  X_CENTER = (cal_X/100);
  Y_CENTER = (cal_Y/100);
  Serial.print("\nCorrection X: ");Serial.print(X_CENTER);
  Serial.print("\nCorrection Y: ");Serial.println(Y_CENTER);
  
  Serial.println("\nplace the joystick in the bottom-left corner");
  X_MIN = 0;    //reset the values
  Y_MIN = 0;
  delay(2500);
  Serial.print("calibrating position");
   for (int i = 0; i < 100; i++) {    //take 100 readings
    Serial.print(".");
    X_MIN += analogRead(joystick_X);
    delay(5);
    Y_MIN += analogRead(joystick_Y);
    delay(5);
  }
  X_MIN /= 100;
  Y_MIN /= 100;
  Serial.println();
  Serial.print("X: "); Serial.println(X_MIN);
  Serial.print("Y: "); Serial.println(Y_MIN);

Serial.println("\nplace the joystick in the top-right corner");
  X_MAX = 0;    //reset the values
  Y_MAX = 0;
  delay(2500);
  Serial.print("calibrating position");
   for (int i = 0; i < 100; i++) {    //take 100 readings
    Serial.print(".");
    X_MAX += analogRead(joystick_X);
    delay(5);
    Y_MAX += analogRead(joystick_Y);
    delay(5);
  }
  X_MAX /=  100;
  Y_MAX /=  100;
  Serial.println();
  Serial.print("X: "); Serial.println(X_MAX);
  Serial.print("Y: "); Serial.println(Y_MAX);

  if(X_MAX < X_MIN){
    unsigned long val = X_MAX;
    X_MAX = X_MIN;
    X_MIN = val;
  }
  if(Y_MAX < Y_MIN){
    unsigned long val = Y_MAX;
    Y_MAX = Y_MIN;
    Y_MIN = val;
  }

  Serial.print("\nrange X: ");Serial.print(X_MIN);Serial.print(" - ");Serial.println(X_MAX);
  Serial.print("range X: ");Serial.print(Y_MIN);Serial.print(" - ");Serial.println(Y_MAX);
    
  Serial.println("\n---calibration done---\n");
}


/*//some people added this function to the Arduino core, comment this if it's already in the Arduino core
float mapfloat(float x, float in_min, float in_max, float out_min, float out_max)
{
  return (x - in_min) * (out_max - out_min) / (in_max - in_min) + out_min;
}
*/

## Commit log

2024-09-26 feat: add joystick button
    also commented out the calibration variables
2024-09-26 feat: update joystick calibration readme
2024-09-26 fix: joystick calibration
    change the output file, remove the blinking light
2024-09-26 feat: add button to disable the drive hiding
2024-09-26 fix: button to hid drive fix
2024-09-27 feat: working on calibration
2024-09-27 feat: FIXED CALIBRATION!
2024-09-27 remove: calibration output file
2024-09-27 fix: update readme to new calibration info
2024-10-01 feat: add some modles
    [Andrew Arcade - Joystick Mount - v1.stl, Andrew Arcade - Joystick Mount - v2.stl, Andrew Arcade - Power Button Mount - v1.stl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]
2024-10-01 feat: joystick mount v3
    [Andrew Arcade - Joystick Mount - v3.stl]
2024-10-02 pcb: working on the pcb
2024-10-02 feat: add flappyturd build
    [Andrew Arcade - Screen Mount - v4.stl]
2024-10-02 feat: worked on pcb
2024-10-04 feat(apps): update driver
2024-10-04 feat: update driver
2024-10-09 feat: working on pcb
2024-10-30 feat(modles): add
    [Andrew Arcade - Front Panel - slicer.3mf, Andrew Arcade - Front Panel.stl, Andrew Arcade - Joystick Mount - v1.stl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]
2024-11-01 feat: update modles
    [Andrew Arcade - Front Panel - slicer.3mf, Andrew Arcade - Front Panel.stl, Andrew Arcade - PIs Mount - slicer.3mf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]
2024-11-02 feat: update models
    [Andrew Arcade - Front Panel - slicer.3mf, Andrew Arcade - Front Panel.stl, Andrew Arcade - Joystick Mount - slicer.3mf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]
2024-11-02 fix: folder name typo
    [Andrew Arcade - Front Panel - slicer.3mf, Andrew Arcade - Front Panel.stl, Andrew Arcade - Joystick Mount - slicer.3mf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]
2024-11-15 feat: export controller schematic
2024-11-16 fix: controller schematic
    [gamepad_pcb.kicad_pcb, gamepad_pcb.kicad_sch]
2024-11-17 fix: controller code
    - reverse +/- buttons
    - negate joystick to have correct directions
2024-11-17 update: apps
    - driver
    - flappyTurd
2024-11-18 fix: driver app
2024-11-19 feat: remove v1 modles, add v2
    [Andrew Arcade - Display Mount - slicer.3mf, Andrew Arcade - Display Mount.stl, Andrew Arcade - Front Panel - slicer.3mf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]
2024-11-21 upd: driver
2024-11-30 feat: build driver
2024-11-30 feat: testing downgraded driver
2024-12-01 upd(software): driver
2024-12-02 upd: models
    [Andrew Arcade - Deck - slicer.3mf, Andrew Arcade - Deck.stl, Andrew Arcade - Display Mount - slicer.3mf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]
2024-12-07 upt: models
    [Andrew Arcade - Deck - slicer.3mf, Andrew Arcade - Deck.stl, Andrew Arcade - Joystick Parts - slicer.3mf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]
2024-12-11 feat: deck files
    [Deck.dxf]
2024-12-11 fix: deck file type
    [Deck.dxf]
2024-12-20 upt: deck model
    [Andrew Arcade - Deck.dxf]
2025-01-11 rmv: unused pcb files
    [gamepad_pcb.kicad_pcb]
2025-01-11 upt(models): convert to bambu
    [Andrew Arcade - Deck - slicer.3mf, Andrew Arcade - Display Mount - slicer.3mf, Andrew Arcade - Display Mount.stl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]
2025-01-23 upt: schematic
    [gamepad_pcb.kicad_sch]
2025-01-23 rmv: schematic auto backup
2025-02-02 upt(software): driver
2025-02-02 fix(software): driver binding
2025-05-21 rmv: old pcb
    [gamepad_pcb.kicad_sch]
2025-05-21 feat: start work on schematic
    [gamepad.kicad_pcb, gamepad.kicad_sch]
2025-05-22 upt(gamepad): working on pcb
    [gamepad.kicad_pcb, gamepad.kicad_sch]
2025-05-23 rmv: download dump
    [Andrew Arcade - Backplate.dxf, Andrew Arcade - Backplate.stl, Andrew Arcade - Deck.dxf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]
2025-05-30 upt: gamepad pcb
    [gamepad.kicad_pcb, gamepad.kicad_sch]
2025-05-30 upt: start wiring schematic
    just gotta make sure it works on a breadboard before ordering a pcb
    [gamepad.kicad_pcb, gamepad.kicad_sch]
2025-05-30 upt: some stuff for the pcb
    - routed the traces
    - cleaned up the wiring for the schematic
    [gamepad.kicad_pcb, gamepad.kicad_sch]
2025-05-31 upt: pcb
    add logo
    [gamepad.kicad_pcb]
2025-06-05 feat: some pcb stuff
    [gamepad.kicad_pcb, gamepad.kicad_sch]
2025-06-05 upt: pico to waveshare zero
    change out the pcb to have a waveshare zero instead of a pico
    [gamepad.kicad_pcb, gamepad.kicad_sch]
2025-06-05 upt: pcb
2025-06-26 feat: pcb stuff
    [bom.csv, designators.csv, gamepad.kicad_pcb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]
2025-07-01 feat: exported pcb files
2025-07-21 feat: smaller pcb
    [designators.csv, gamepad.kicad_pcb, gamepad.kicad_sch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]
2025-08-10 feat: firmware backup
    to use on other devices to setup the firmware quicker
2025-08-10 fix: swap pcb left/right
    [gamepad.kicad_pcb, gamepad.kicad_sch]
2025-10-03 feat: add models
    [Back Plate.step, Display Mount.step, Front Panel.step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]
2025-10-03 rmv: driver app instructions
2026-05-13 working on simple pcb
2026-05-13 Revert "working on simple pcb"
    This reverts commit e8ce82c8a07d9a8eb121910e16f9c7b1daafe766.
